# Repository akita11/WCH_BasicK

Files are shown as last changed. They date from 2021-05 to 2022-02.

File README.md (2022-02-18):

# WCH_BasicK

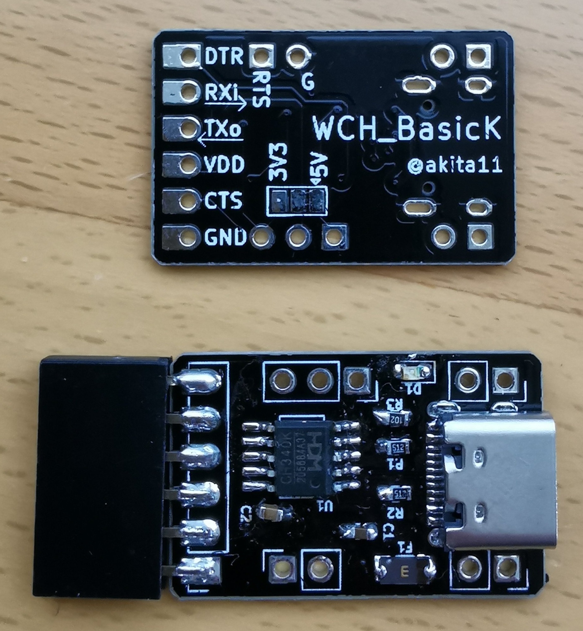
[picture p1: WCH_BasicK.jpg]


## これは何？

- [中国のWCH社](http://www.wch-ic.com/)の格安USB-シリアル変換チップCH340Kを使った、USB-シリアル変換器です。
- Arduino等の書き込みやシリアル通信で、標準的に使われる[FTDI Basic](https://www.switch-science.com/catalog/342/)と同じ6ピンコネクタを備えています。
- PC側のコネクタはUSB Type-Cです。
- FTDI Basic互換の6ピンコネクタ以外に、ESP32の書き込み等で用いられるRTS#信号を、脇の端子に引き出してありますので、必要な場合はそこにコネクタ等を接続して利用できます。
- FTDI Basic互換の6ピンコネクタのVDD端子に供給される電圧は、5Vと3.3Vから選択できます。（初期設定は5V）

## 使い方

- （必要であれば同梱の6pソケットをはんだ付けします。）
- [WCH社のドライバのダウンロードサイト](http://www.wch-ic.com/search?q=CH340&t=downloads)から最新のドライバをインストールしておきます。※一部サイトで、古いバージョンのドライバへのリンクが貼られているところがあります。接続後のドライバのインストールに失敗する場合は、最新のドライバをインストールします。
- 市販のUSB Type-Cコネクタを持つケーブルでPCと接続し、ArduinoIDEのシリアルモニタ等のCOMポートを用いるアプリケーションから使用します。
- 【注意】送受信などの制御信号線のHレベルは5Vで固定です（次バージョンでVDDに連動するよう修正予定）

## 使い方（オプション）
- RTS#信号を使用する場合は、基板上のRTS#と示した箇所のランドを使用してください。なおその脇にはGND端子があります。
- 6pコネクタのVDD端子の供給電圧を初期設定の5Vから3.3Vに変更する場合は、裏面ソルダージャンパの「中央-5V間」をカッター等で切断し、「中央-3.3V間」をハンダで接続してください。または切り離した状態で、脇の3p端子にピンヘッダ等を取り付けて3.3V/5Vを切り替えられるようにしてください。
- USB Type-Cコネクタ脇の2組の2p端子は無接続です。ブレッドボード等に固定するヘッダピンを取り付けるなどに使用できます。

## （自作する方向け）作り方

- 基板データ(KiCAD)またはそこから生成したガーバーデータを使って、基板を製造します。
- 部品を入手します。
  - [CH340K](https://akizukidenshi.com/catalog/g/gI-16306/)
  - [USB Type-Cコネクタ](https://akizukidenshi.com/catalog/g/gC-14356/)
  - 0.1uFチップコンデンサ(1608サイズ)：：2個
  - 1kΩチップ抵抗(1608サイズ)
  - 5.1kΩチップ抵抗(1608サイズ)：2個
  - 緑チップLED(1608サイズ)
  - [350mAポリスイッチ(3216サイズ)](https://akizukidenshi.com/catalog/g/gP-13490/)
  - [ピンソケット6p](https://akizukidenshi.com/catalog/g/gC-03784/)
- 基板上に部品をとりつけます。

## Author

Junichi Akita (akita@ifdl.jp, @akita11)

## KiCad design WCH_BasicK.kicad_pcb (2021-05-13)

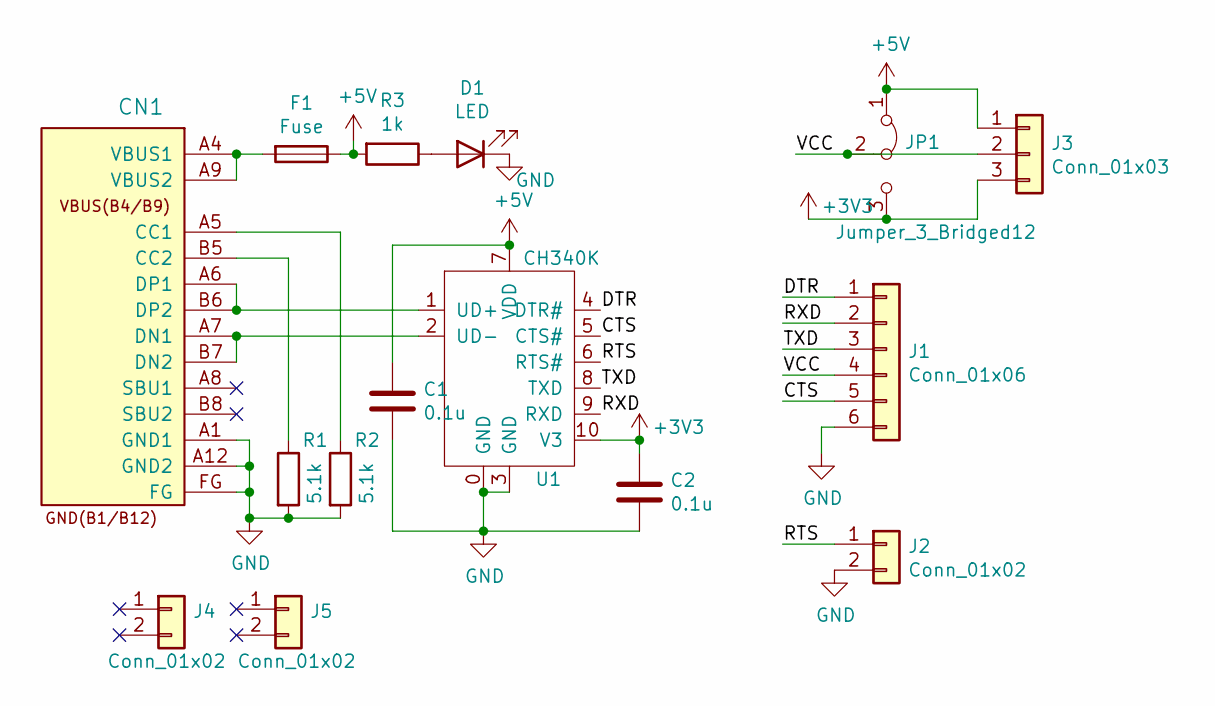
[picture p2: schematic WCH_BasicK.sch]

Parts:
C1, C2: 0.1u; C_0603_1608Metric
CN1: CON_USB-C-16; USB-C_16P_TH
D1: LED; LED_0603_1608Metric
F1: Fuse; Fuse_1206_3216Metric
J1: Conn_01x06; PinSocket_1x06_P2.54mm_Vertical
J2, J4, J5: Conn_01x02; PinSocket_1x02_P2.54mm_Vertical
J3: Conn_01x03; PinSocket_1x03_P2.54mm_Vertical
JP1: Jumper_3_Bridged12; SolderJumper-3_P1.3mm_Bridged2Bar12_Pad1.0x1.5mm
R1, R2: 5.1k; R_0603_1608Metric
R3: 1k; R_0603_1608Metric
U1: CH340K; ESOIC-10_P1.0mm

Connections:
+3V3: C2.1, J3.3, JP1.3 (B), U1.10 (V3)
+5V: C1.1, F1.1, J3.1, JP1.1 (A), R3.2, U1.7 (VDD)
/CTS: J1.5, U1.5 (CTS#)
/DTR: J1.1, U1.4 (DTR#)
/RTS: J2.1, U1.6 (RTS#)
/RXD: J1.2, U1.9 (RXD)
/TXD: J1.3, U1.8 (TXD)
/VCC: J1.4, J3.2, JP1.2 (C)
GND: C1.2, C2.2, CN1.A1 (GND1), CN1.A12 (GND2), CN1.FG, D1.1 (K), J1.6, J2.2, R1.2, R2.2, U1.0 (GND), U1.3 (GND)
unnamed: CN1.A4 (VBUS1), CN1.A9 (VBUS2), F1.2
unnamed: CN1.A5 (CC1), R2.1
unnamed: CN1.A6 (DP1), CN1.B6 (DP2), U1.1 (UD+)
unnamed: CN1.A7 (DN1), CN1.B7 (DN2), U1.2 (UD-)
unnamed: CN1.B5 (CC2), R1.1
unnamed: D1.2 (A), R3.1

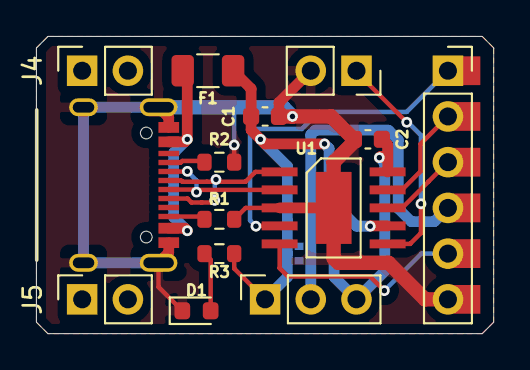
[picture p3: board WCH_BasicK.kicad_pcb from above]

Board: 2 copper layers, 25.4 x 16.5 mm, 15 parts (1 on the bottom side), 15 nets.

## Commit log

2021-05-13 Add files via upload
    initial commit
    [WCH_BasicK.kicad_pcb, WCH_BasicK.sch]
2021-05-26 写真の追加
2021-05-26 README.mdのリンクを修正
